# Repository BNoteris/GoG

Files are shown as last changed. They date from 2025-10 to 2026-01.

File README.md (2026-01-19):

# LoRa GPS IoT — PCB Proof-of-Concept

This repository hosts the LoRa GPS IoT proof-of-concept developed as the final project of the High Frequency Circuit Design course at ECAM.
The system integrates a GPS receiver, an ESP32 microcontroller, and a LoRa transceiver to provide location reporting over the LoRaWAN 868 MHz band.
A dedicated custom PCB antenna was designed, simulated and produced for LoRa operation at 868 MHz 
The design was specified in collaboration with an industrial partner and implemented on a 2‑layer FR4 PCB.
Every tool used during this project was open-source.

<div align="center">

</div>

All KiCad & gerber files are available in the [hardware](/hardware) directory.

Antenna simulation can be found in [software](/software).

## Specifications

- Provide GPS-based localization transmission over LoRa at the 868 MHz European LoRa frequency band.
- Support Wi-Fi/BLE communication with ESP32 provided antenna.
- Support multiple power inputs: USB‑C, external battery (2S), and solar panel input.
- Create a compact PCB (≤ 10×10 cm for fabrication on JLCPCB) as a proof of concept.
- Create a custom Inverted‑F Antenna (IFA) tuned to 868 MHz.

## Hardware used

- **ESP32‑C3‑WROOM‑02** — main MCU (USB‑C programming and Wi‑Fi/BLE). Supports SPI and I²C for peripheral interfaces.
- **RFM95 (LoRa) module** — 868 MHz LoRa transceiver (module used without on‑board antenna; external/custom antenna on separate antenna PCB).
- **GPS module AM‑M8Q‑0** — GNSS receiver for latitude/longitude acquisition.
- **BQ25798** — battery charger/power manager supporting USB‑C and solar inputs, designed for a 2S battery configuration.
- **USB‑C connector** — for programming and charging.
- **SMA connector** — RF connector for the custom antenna / external antenna.

## Antenna simulation & testing
### Simulation

Electromagnetic simulations were performed using the Emerge Python‑based EM tool to optimize the antenna geometry for maximum radiated power and minimal reflection at the target frequency.

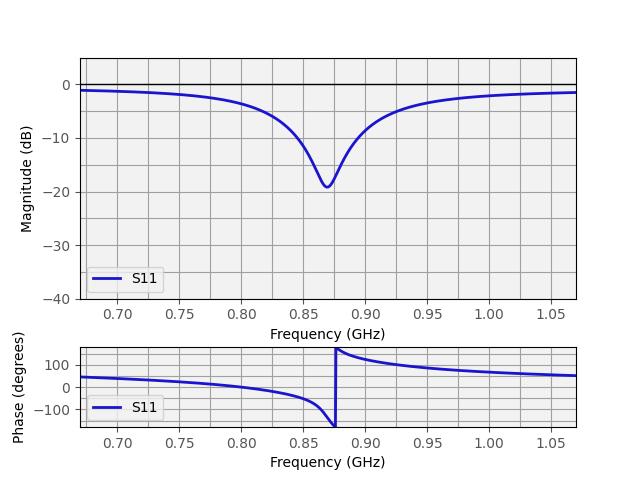
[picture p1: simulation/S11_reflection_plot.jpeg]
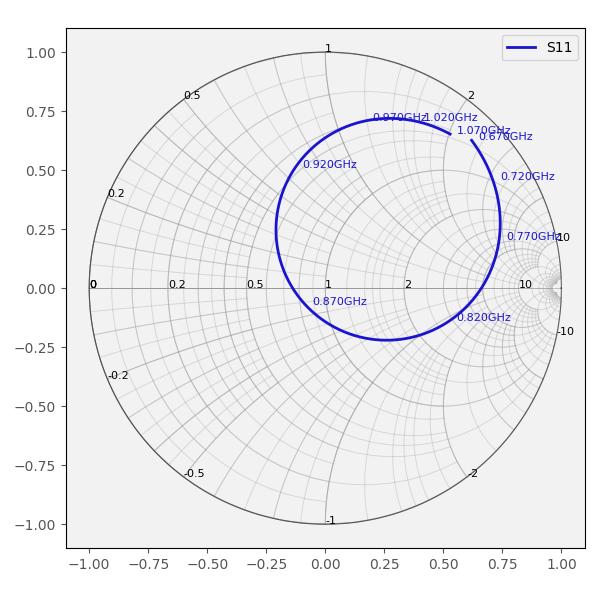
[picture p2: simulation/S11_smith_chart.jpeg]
 | 
:------------:|:--------------------------:
S11 reflection coefficient | Smith chart of reflection coefficient

Primary performance metrics from simulation:
- Minimum simulated **S₁₁ = −17.75 dB at 868 MHz**.
- **−10 dB impedance bandwidth ≈ 50 MHz**, which covers the LoRaWAN band with margin for manufacturing tolerances.

The simulated Smith chart shows the antenna impedance close to the center (near 50 Ω) at 868 MHz; minor adjustments were left open to address real‑world feed/feedline/environment effects.

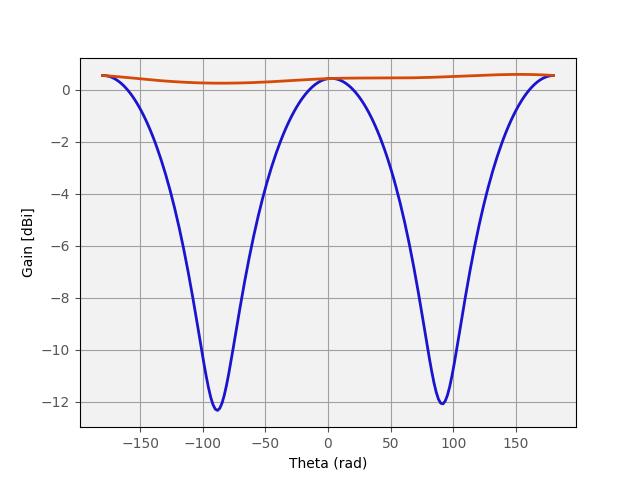
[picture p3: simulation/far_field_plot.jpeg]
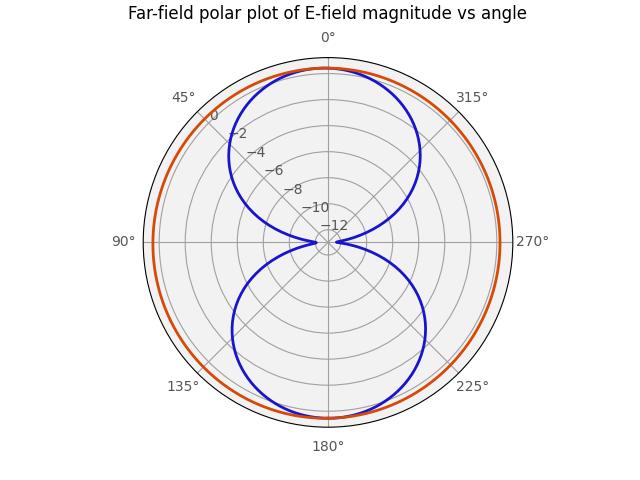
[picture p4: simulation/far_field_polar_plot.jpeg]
 | 
:-----------:|:-------------------:
Far-Field E  |  Polar Far-Field E

<div align="center">
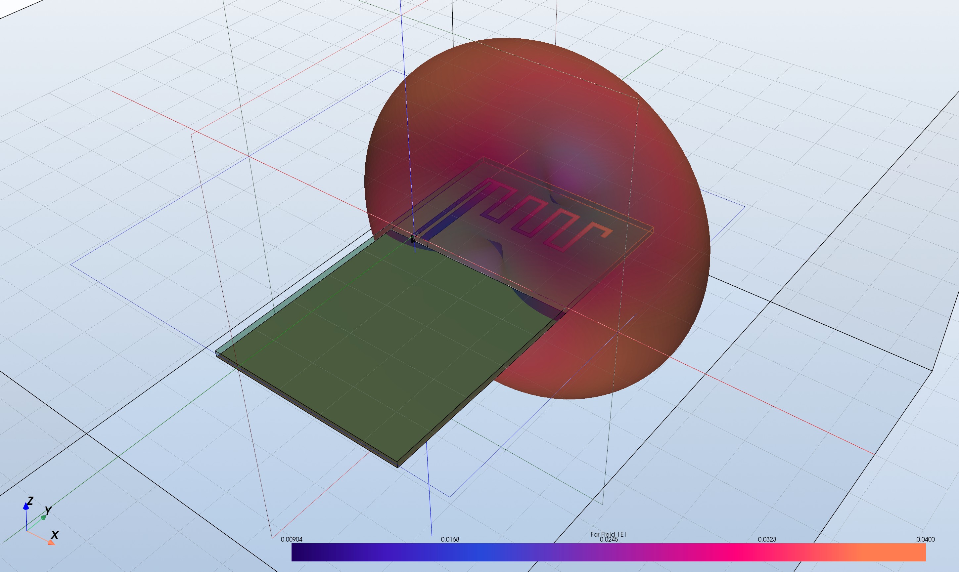
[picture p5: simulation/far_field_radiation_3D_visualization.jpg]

</div>

Far‑field results (normalized E‑field, polar plots and 3D radiation pattern) were generated to verify radiation behaviour

### Hardware validation

<div align="center">

</div>

The manufactured IFA PCB was integrated into the system and validated using a Digital Spectrum Analyzer (DSA) by observing a distinct spectral peak at 868 MHz aligned with the transmission cadence when our custom antenna is sending its packet to a reference antenna tuned to the same band.

 | 
:-------------------------------------------------:|:---------------------------------------------:
Spectrum analysis without custom antenna emission  | Spectrum analysis with custom antenna emission 

Results confirm that the antenna radiates at the intended operating frequency.
Minor nearby spectral peaks were attributed to ambient RF activity.

Limitations: a Vector Network Analyzer (VNA) was not available during testing, preventing direct measurement of the antenna reflection coefficient (S₁₁) on the manufactured part.
This measurement is recommended for a definitive comparison against simulation.

## Improvements

Several enhancements could be considered to further improve the system’s performance 
and quality: 
- As the PCB was intentionally designed with only 2 layers and no ground/power 
planes to observe and measure EMI, but has finally not been done, upgrading our 
design to 4 layers with copper planes would simplify the PCB layout and improve 
EMC. It would, consequently, allow for a more compact design, making it more 
practical.
- Testing our system to EMI interferences would allow to have a better knowledge of 
its real-world performance, as well as its capability to respect HF regulations, a 
mandatory step to deliver our product to the market. 
- Access to a Vector Network Analyzer (or even a LiteVNA) would enable precise 
measurements of the antenna reflection coefficient and matching impedance, 
allowing direct comparison with simulation results and more accurate impedance 
tuning. 
- Testing the system in a real-world environment would provide more information on 
its robustness, in particular, packet loss and communication range and 
performance.

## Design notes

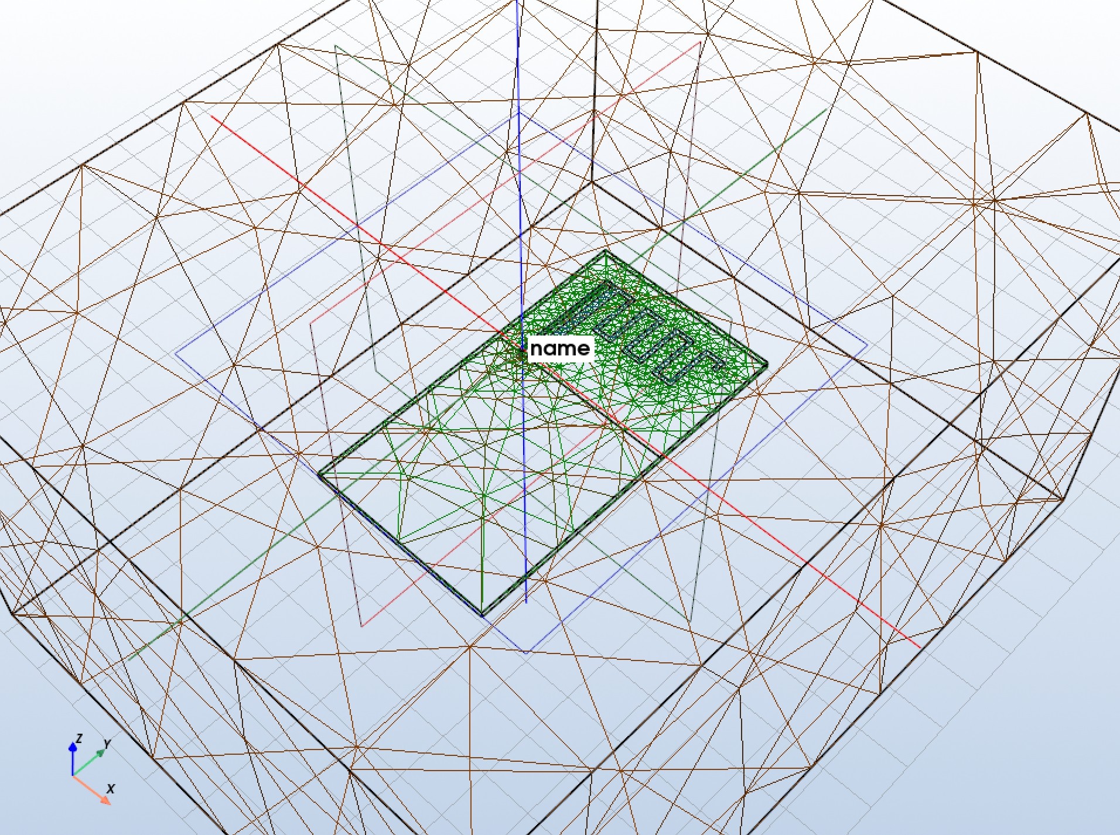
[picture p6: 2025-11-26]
simulation/antenna_mesh_view.jpg

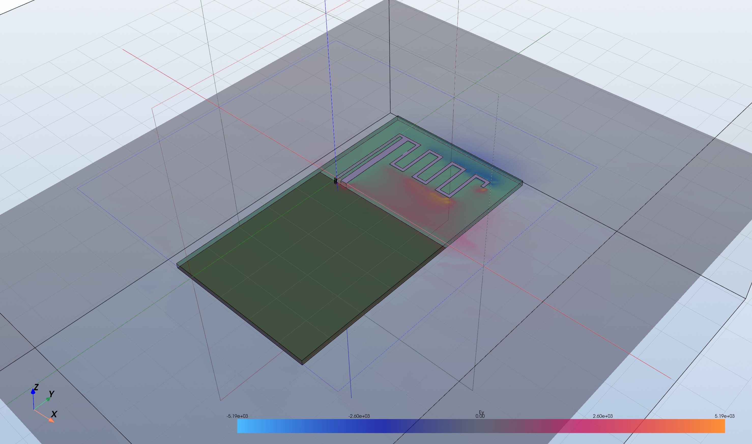
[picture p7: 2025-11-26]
simulation/Ey_3D_visualization.jpg

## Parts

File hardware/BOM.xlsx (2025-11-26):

Reference | Value | Footprint | Description | Qty | JLCPCB Part # | Package
C1 | 10µF | Capacitor_SMD:C_0603_1608Metric | CL10A106MA8NRNC 10uF 25V X5R ±20% 0603 Multilayer Ceramic Capacitor | 1 | C96446 | 0603
C10,C11,C12,C13,C14,C21,C22,C23,C24,C25,C26,C27 | 10u | Capacitor_SMD:C_0805_2012Metric | CL21A106KAYNNNE 10uF 25V X5R ±10% 0805 Multilayer Ceramic Capacitor | 12 | C15850 | 0805
C16,C19 | 47n | GoG_Library:C_0402_1005Metric_JLCPCB | CC0402KRX7R8BB473 25V 47nF X7R ±10% 0402 Multilayer Ceramic Capacitor | 2 | C107020 | 0402
C17 | 4.7u | Capacitor_SMD:C_0603_1608Metric | CL10A475KP8NNNC 10V 4.7uF X5R ±10% 0603 Multilayer Ceramic Capacitor | 1 | C1705 | 0603
C2 | 0.1µF | Capacitor_SMD:C_0603_1608Metric | CL10B104KA8NNNC 100nF 25V X7R ±10% 0603 Multilayer Ceramic Capacitors MLCC - SMD/SMT ROHS | 1 | C1590 | 0603
C28 | 1n | GoG_Library:C_0402_1005Metric_JLCPCB | CL05B102KB5NNNC 1nF 50V X7R ±10% 0402 Multilayer Ceramic Capacitor | 1 | C14442 | 0402
C29 | 0.1u | Capacitor_SMD:C_0603_1608Metric | CC0603KRX7R9BB104 100nF 50V X7R ±10% 0603 Multilayer Ceramic Capacitor | 1 | C14663 | 0603
C3,C7 | 1µF | Capacitor_SMD:C_0603_1608Metric | CL10B105KA8NNNC 1uF 25V X7R ±10% 0603 Multilayer Ceramic Capacitor | 2 | C29936 | 0603
C30 | 10u | Capacitor_SMD:C_0805_2012Metric | HGC0805R5106K350NSLJ 10uF 35V X5R ±10% 0805 Multilayer Ceramic Capacitor | 1 | C33546007 | 0805
C31,C32 | 22u | Capacitor_SMD:C_0805_2012Metric | CL21A226MAQNNNE 22uF 25V X5R ±20% 0805 Multilayer Ceramic Capacitor | 2 | C45783 | 0805
C4 | 100nF | Capacitor_SMD:C_0603_1608Metric | CL10B104KA8NNNC 100nF 25V X7R ±10% 0603 Multilayer Ceramic Capacitors MLCC - SMD/SMT ROHS | 1 | C1590 | 0603
C5,C6 | (NC) | Resistor_SMD:R_0805_2012Metric_Pad1.20x1.40mm_HandSolder | Unpolarized capacitor | 2 | / | 0805 | Non connect capacitors for antenna : Remove from assembly BOM
C8,C9,C15,C18,C20 | 0.1u | GoG_Library:C_0402_1005Metric_JLCPCB | CL05A104KA5NNNC 100nF 25V X5R ±10% 0402 Multilayer Ceramic Capacitor | 5 | C100072 | 0402
D1,D2 | R_LED | LED_SMD:LED_0603_1608Metric | MEIHUA MHT192DUGCT LED 2.3V~2.8V 518nm 565mcd 5mA 60mW Green | 2 | C7470862 | 0603
D3 | D_Zener | Diode_SMD:D_SOD-123 | ONSEMI MMSZ4697T1G Zener diode 10V 1uA@7.6V 500mW 9.5V~10.5V | 1 | C48870 | SOD-123
D4,D5 | D_Zener | Diode_SMD:D_SOD-123 | ONSEMI MMSZ4699T1G Zener diode 12V 500mW 50nA@9.1V | 2 | C97772 | SOD-123
D6 | LED | LED_SMD:LED_0603_1608Metric | MEIHUA MHT192DUGCT LED 2.3V~2.8V 518nm 565mcd 5mA 60mW Green | 1 | C7470862 | 0603
J1 | USB_C_Receptacle_USB2.0_16P | Connector_USB:USB_C_Receptacle_GCT_USB4105-xx-A_16P_TopMnt_Horizontal | TYPE-C16PIN USB 2.0-only 16P Type-C Receptacle connector | 1 | C393939 | SMD
J10 | Conn_01x03 | Connector_PinHeader_2.54mm:PinHeader_1x03_P2.54mm_Vertical | ZX-PZ2.54-1-3PZZ 1x3P 2.54mm Pin Header | 1 | C7501261 | Plugin,P=2.54mm
J11 | Conn_01x02 | Connector_PinHeader_2.54mm:PinHeader_1x02_P2.54mm_Vertical | ZX-PZ2.54-1-2PZZ 1x2P 2.54mm Pin Header | 1 | C7501260 | Plugin,P=2.54mm
J2,J4 | Conn_01x02_Pin | Connector_PinHeader_2.54mm:PinHeader_1x02_P2.54mm_Vertical | ZX-PZ2.54-1-2PZZ 1x2P 2.54mm Pin Header | 2 | C7501260 | Plugin,P=2.54mm
J3 | Conn_01x04_Pin | Connector_PinHeader_2.54mm:PinHeader_1x04_P2.54mm_Vertical | ZX-PZ2.54-1-4PZZ 1x4P 2.54mm Pin Header | 1 | C7501262 | Plugin,P=2.54mm
J5 | 85201239 | SMA-85201239:HUBER_SUHNER_85201239 | -45℃~+80℃ 1 14.6mm 4.65mm 50Ω 6GHz Board Side Inner Bore Plugin Coaxial Connectors (RF) ROHS | 1 | C7498154 | Plugin
J6,J7 | Conn_01x04_Pin | Connector_JST:JST_XH_B4B-XH-A_1x04_P2.50mm_Vertical | B4B-XH-AM(LF)(SN) 1x4P 2.5mm JST connector | 2 | C161871 | Plugin,P=2.5mm
J8 | Screw_Terminal_01x02 | GoG_Library:TerminalBlock_WJ126V-5.0-2P_1x02_P5.00mm | WJ126V-5.0-2P 1x2P P=5mm Screw Terminal Block | 1 | C8404 | Plugin,P=5mm
J9 | Conn_01x02 | Connector_JST:JST_XH_B2B-XH-A_1x02_P2.50mm_Vertical | B2B-XH-A(LF)(SN) 1x2P P=2.5mm XH JST connector | 1 | C158012 | Plugin,P=2.5mm
L1 | 2.2u | GoG_Library:MDA5030-2R2M | MDA5030-2R2M Inductor 2.2uH 21.6mΩ 6.5A 6.5A ±20% SMD, 5.7x5.2mm | 1 | C2847475 | SMD, 5.7x5.2mm
L2 | 3.9u | Inductor_SMD:L_Sunlord_SWPA4030S | SWPA4030S3R9MT 2.1A 3.9uH 3A 74mΩ ±20% SMD,4x4mm Power Inductor | 1 | C96899 | SMD, 4x4mm
Q1 | Q_PMOS | Package_TO_SOT_SMD:SOT-23 | P-MOSFET transistor | 1 | C5350989 | SOT-23
Q2,Q3,Q4,Q5 | Q_NMOS | Package_TO_SOT_SMD:SOT-23 | N-MOSFET transistor | 4 | C2938367 | SOT-23
R1,R10 | 1k | Resistor_SMD:R_0603_1608Metric | RC0603FR-071KL 100mW 1kΩ 75V Thick Film Resistor ±1% 0603 | 2 | C22548 | 0603
R11,R12 | 470 | Resistor_SMD:R_0603_1608Metric | RC0603FR-07470RL 100mW 470Ω 75V Thick Film Resistor ±1% 0603 | 2 | C114669 | 0603
R13,R14 | 22 | Resistor_SMD:R_0603_1608Metric | RC0603FR-0722RL 100mW 22Ω 75V Thick Film Resistor ±1% 0603 | 2 | C107701 | 0603
R15,R17 | 300 | Resistor_SMD:R_0603_1608Metric | RC0603FR-07300RL -55℃~+155℃ 100mW 300Ω 75V Thick Film Resistor ±1% ±100ppm/℃ 0603 | 2 | C114617 | 0603
R16,R25 | 100k | GoG_Library:R_0402_1005Metric_JLCPCB | RC0402FR-07100KL -55℃~+155℃ 100kΩ 50V 62.5mW Thick Film Resistor ±1% ±100ppm/℃ 0402 | 2 | C60491 | 0402
R18 | 10k | GoG_Library:R_0402_1005Metric_JLCPCB | RC0402FR-0710KL -55℃~+155℃ 10kΩ 50V 62.5mW Thick Film Resistor ±1% ±100ppm/℃ 0402 | 1 | C60490 | 0402
R19 | 2.2k | GoG_Library:R_0402_1005Metric_JLCPCB | RC0402JR-072K2L -55℃~+155℃ 2.2kΩ 50V 62.5mW Thick Film Resistor ±100ppm/℃ ±5% 0402 | 1 | C163447 | 0402
R2,R3,R6 | 10k | Resistor_SMD:R_0603_1608Metric | RC0603FR-0710KL 100mW 10kΩ 75V Thick Film Resistor ±1% 0603 | 3 | C98220 | 0603
R20 | 100 | GoG_Library:R_0402_1005Metric_JLCPCB | RC0402FR-07100RL -55℃~+155℃ 100Ω 50V 62.5mW Thick Film Resistor ±1% ±100ppm/℃ 0402 | 1 | C106232 | 0402
R21 | 5.1k | GoG_Library:R_0402_1005Metric_JLCPCB | RC0402FR-075K1L -55℃~+155℃ 5.1kΩ 50V 62.5mW Thick Film Resistor ±1% ±100ppm/℃ 0402 | 1 | C105872 | 0402
R22 | 120k | GoG_Library:R_0402_1005Metric_JLCPCB | RC0402FR-07120KL -55℃~+155℃ 120kΩ 50V 62.5mW Thick Film Resistor ±1% ±100ppm/℃ 0402 | 1 | C93945 | 0402
R23 | 8.2k | GoG_Library:R_0402_1005Metric_JLCPCB | RC0402FR-078K2L -55℃~+155℃ 50V 62.5mW 8.2kΩ Thick Film Resistor ±1% ±100ppm/℃ 0402 | 1 | C137929 | 0402
R24 | 30k | GoG_Library:R_0402_1005Metric_JLCPCB | RC0402FR-0730KL -55℃~+155℃ 30kΩ 50V 62.5mW Thick Film Resistor ±1% ±100ppm/℃ 0402 | 1 | C138008 | 0402
R4,R5 | 4.7k | Resistor_SMD:R_0603_1608Metric | RC0603FR-074K7L 100mW 4.7kΩ 75V Thick Film Resistor ±1% 0603 | 2 | C99782 | 0603
R7,R8 | 5k1 | Resistor_SMD:R_0603_1608Metric | RC0603FR-075K1L 100mW 5.1kΩ 75V Thick Film Resistor ±1% 0603 | 2 | C105580 | 0603
R9 | 0 | Resistor_SMD:R_0805_2012Metric_Pad1.20x1.40mm_HandSolder | PMR10EZPJ000 0Ω 500mW Shunt Resistor 0805 | 1 | C2842889 | 0805
SW1,SW2 | SW_Omron_B3FS | Button_Switch_SMD:SW_SPST_Omron_B3FS-101xP | Omron B3FS-1010P 6x6mm single pole normally-open tactile switch | 2 | C231324 | SMD-4P,6.3x6mm
TH1 | 10k | GoG_Library:Thermistor NTC | Vishay NTCLE413E2103F102L NTC Thermistor 10k 3435K | 1 | - | - | Get from Farnell : 2492885
U1 | ESP32-C3-WROOM-02 | RF_Module:ESP32-C3-WROOM-02 | 802.11 b/g/n Wi-Fi and Bluetooth 5 module, ESP32-C3 SoC, RISC-V microprocessor, On-board antenna | 1 | C2934560 | LCC-18
U2 | USBLC6-2SC6 | Package_TO_SOT_SMD:SOT-23-6 | USBLC6-2SC6 Very low capacitance ESD protection diode, 2 data-line, SOT-23-6 | 1 | C7519 | SOT-23-6L
U3 | RFM95W-868S2 | GoG_Library:HOPERF_RFM9XW_SMD | Low power long range transceiver module, SPI and parallel interface, 868 MHz, spreading factor 6 to12, bandwidth 7.8 to 500kHz, -111 to -148 dBm, SMD-16, DIP-16 | 1 | C2844472 | SMD,16x16mm
U4 | SAM-M8Q | RF_GPS:ublox_SAM-M8Q | GPS ublox M8 variant | 1 | C5447387 | SMD-20P,15x15mm | Out of stock
U5 | BQ25798RQMR | BQ25798RQMR:IC_BQ25798RQMR | -40℃~+85℃ 17uA 1~4 3.6V~24V 5A Charging IC I2C Lithium Battery Support QFN-29(4x4) Battery Management | 1 | C2876593 | QFN-29(4x4) | Out of stock
U6 | AP63203WU | Package_TO_SOT_SMD:TSOT-23-6 | 2A, 1.1MHz Buck DC/DC Converter, fixed 3.3V output voltage, TSOT-23-6 | 1 | C780769 | TSOT-23-6

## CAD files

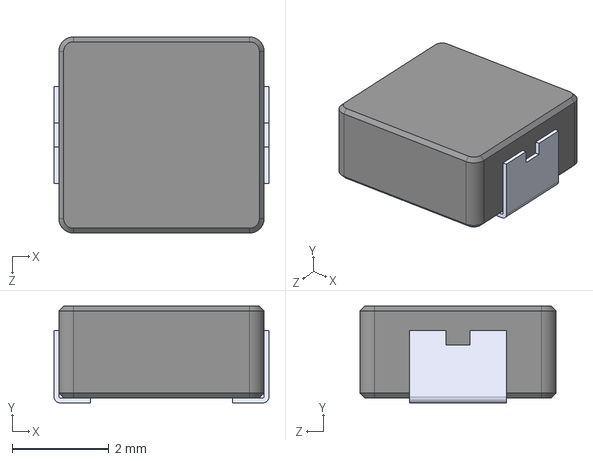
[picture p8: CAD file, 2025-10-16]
hardware/Project library/SRP4020TA-5R6M/SRP4020TA-5R6M.step
4.45 x 2.00 x 4.06 mm

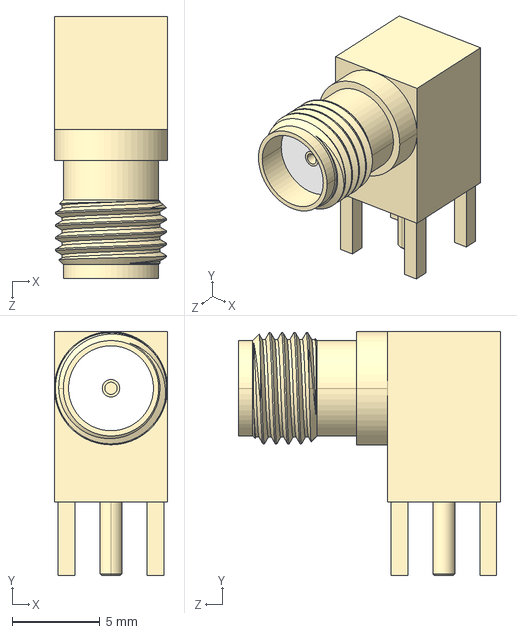
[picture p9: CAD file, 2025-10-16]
hardware/Project library/SMA-85201239/85201239.step
6.46 x 13.9 x 15.0 mm

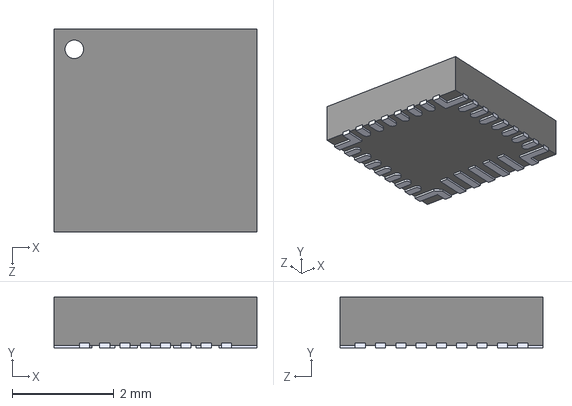
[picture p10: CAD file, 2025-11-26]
hardware/Project library/ul_BQ25798RQMR/KiCADv6/BQ25798RQMR.step
4.00 x 1.00 x 4.00 mm

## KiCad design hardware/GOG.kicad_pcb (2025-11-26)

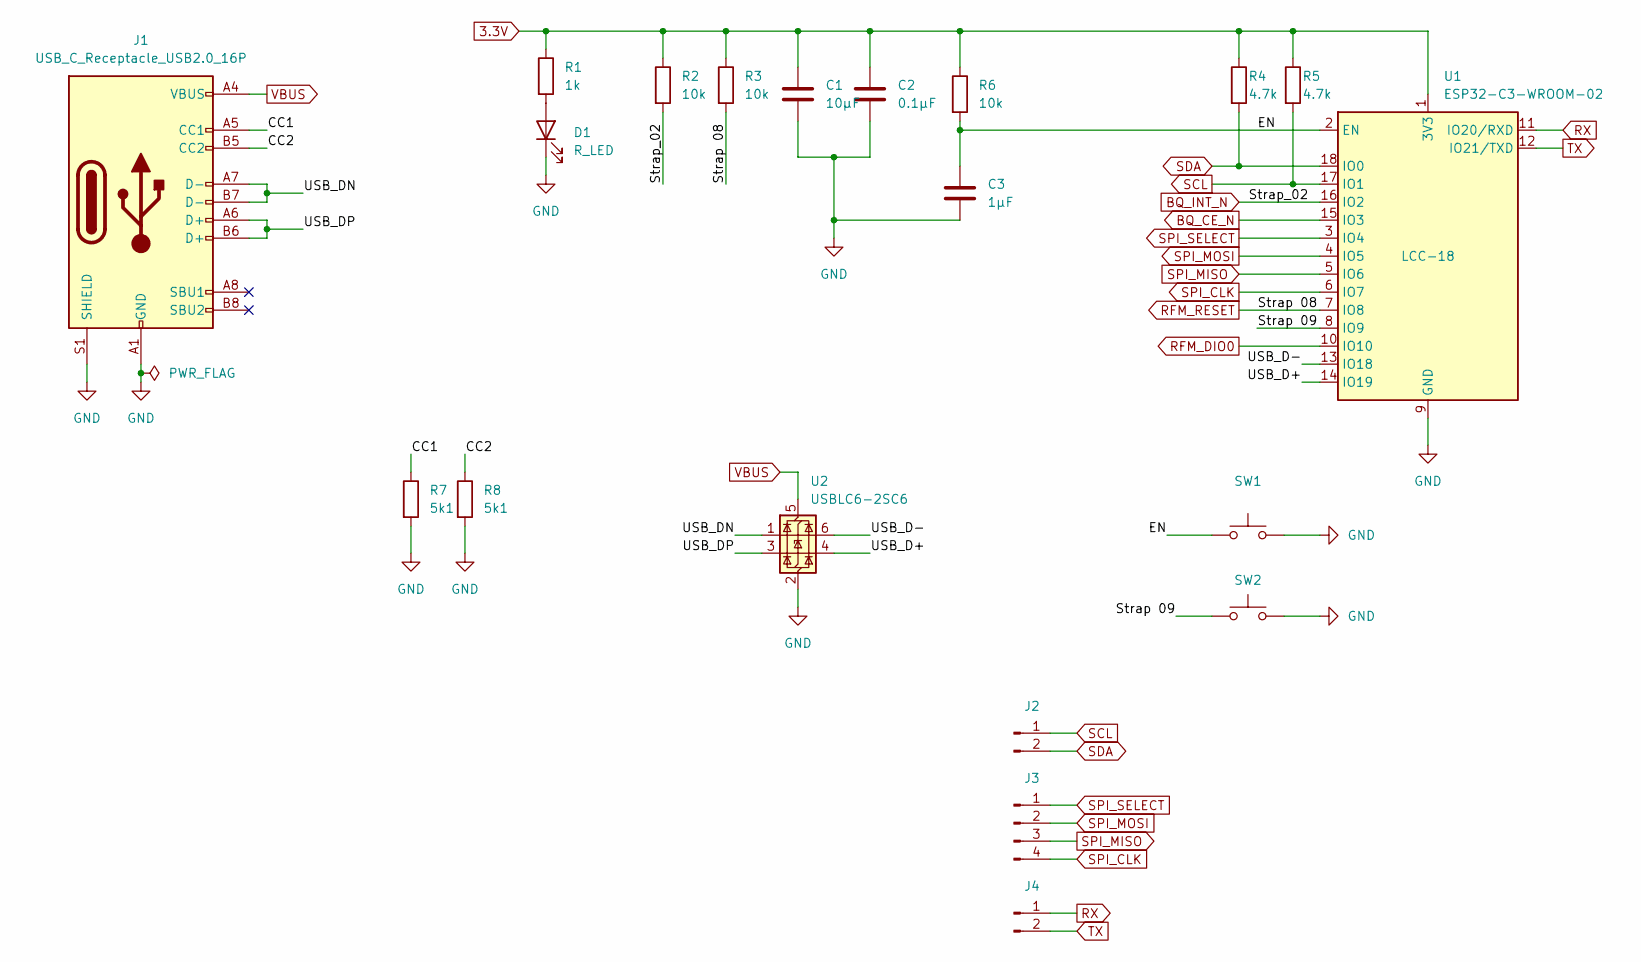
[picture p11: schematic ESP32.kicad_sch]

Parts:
C1: 10µF; C_0603_1608Metric; JLCPCB Part # C96446
C2: 0.1µF; C_0603_1608Metric; JLCPCB Part # C1590
C3: 1µF; C_0603_1608Metric; JLCPCB Part # C29936
D1: R_LED; LED_0603_1608Metric; JLCPCB Part # C7470862
J1: USB_C_Receptacle_USB2.0_16P; USB_C_Receptacle_GCT_USB4105-xx-A_16P_TopMnt_Horizontal; JLCPCB Part # C393939
J2, J4: Conn_01x02_Pin; PinHeader_1x02_P2.54mm_Vertical; JLCPCB Part # C7501260
J3: Conn_01x04_Pin; PinHeader_1x04_P2.54mm_Vertical; JLCPCB Part # C7501262
R1: 1k; R_0603_1608Metric; JLCPCB Part # C22548
R2, R3, R6: 10k; R_0603_1608Metric; JLCPCB Part # C98220
R4, R5: 4.7k; R_0603_1608Metric; JLCPCB Part # C99782
R7, R8: 5k1; R_0603_1608Metric; JLCPCB Part # C105580
SW1, SW2: SW_Omron_B3FS; SW_SPST_Omron_B3FS-101xP; JLCPCB Part # C231324
U1: ESP32-C3-WROOM-02; JLCPCB Part # C2934560
U2: USBLC6-2SC6; SOT-23-6; JLCPCB Part # C7519

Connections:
3.3V: C1.1, C2.1, R1.1, R2.1, R3.1, R4.1, R5.1, R6.1, U1.1 (3V3); also elsewhere on the board
/ESP32/CC1: J1.A5 (CC1), R7.1
/ESP32/CC2: J1.B5 (CC2), R8.1
/ESP32/EN: C3.1, R6.2, SW1.1, U1.2 (EN)
/ESP32/Strap 09: SW2.1, U1.8 (IO9)
/ESP32/USB_D+: U1.14 (IO19), U2.4 (I/O2)
/ESP32/USB_D-: U1.13 (IO18), U2.6 (I/O1)
/ESP32/USB_DN: J1.A7 (D-), J1.B7 (D-), U2.1 (I/O1)
/ESP32/USB_DP: J1.A6 (D+), J1.B6 (D+), U2.3 (I/O2)
BQ_CE_N: U1.15 (IO3); also elsewhere on the board
BQ_INT_N: R2.2, U1.16 (IO2); also elsewhere on the board
GND: C1.2, C2.2, C3.2, D1.1 (K), J1.A1 (GND), J1.A12 (GND), J1.B1 (GND), J1.B12 (GND), J1.S1 (SHIELD), R7.2, R8.2, SW1.2, SW2.2, U1.9 (GND), U1.19 (GND), U2.2 (GND); also elsewhere on the board
unnamed: D1.2 (A), R1.2
RFM_DIO0: U1.10 (IO10); also elsewhere on the board
RFM_RESET: R3.2, U1.7 (IO8); also elsewhere on the board
RX: J4.1, U1.11 (IO20/RXD)
SCL: J2.1, R5.2, U1.17 (IO1); also elsewhere on the board
SDA: J2.2, R4.2, U1.18 (IO0); also elsewhere on the board
SPI_CLK: J3.4, U1.6 (IO7); also elsewhere on the board
SPI_MISO: J3.3, U1.5 (IO6); also elsewhere on the board
SPI_MOSI: J3.2, U1.4 (IO5); also elsewhere on the board
SPI_SELECT: J3.1, U1.3 (IO4); also elsewhere on the board
TX: J4.2, U1.12 (IO21/TXD)
VBUS: J1.A4 (VBUS), J1.A9 (VBUS), J1.B4 (VBUS), J1.B9 (VBUS), U2.5 (VBUS); also elsewhere on the board

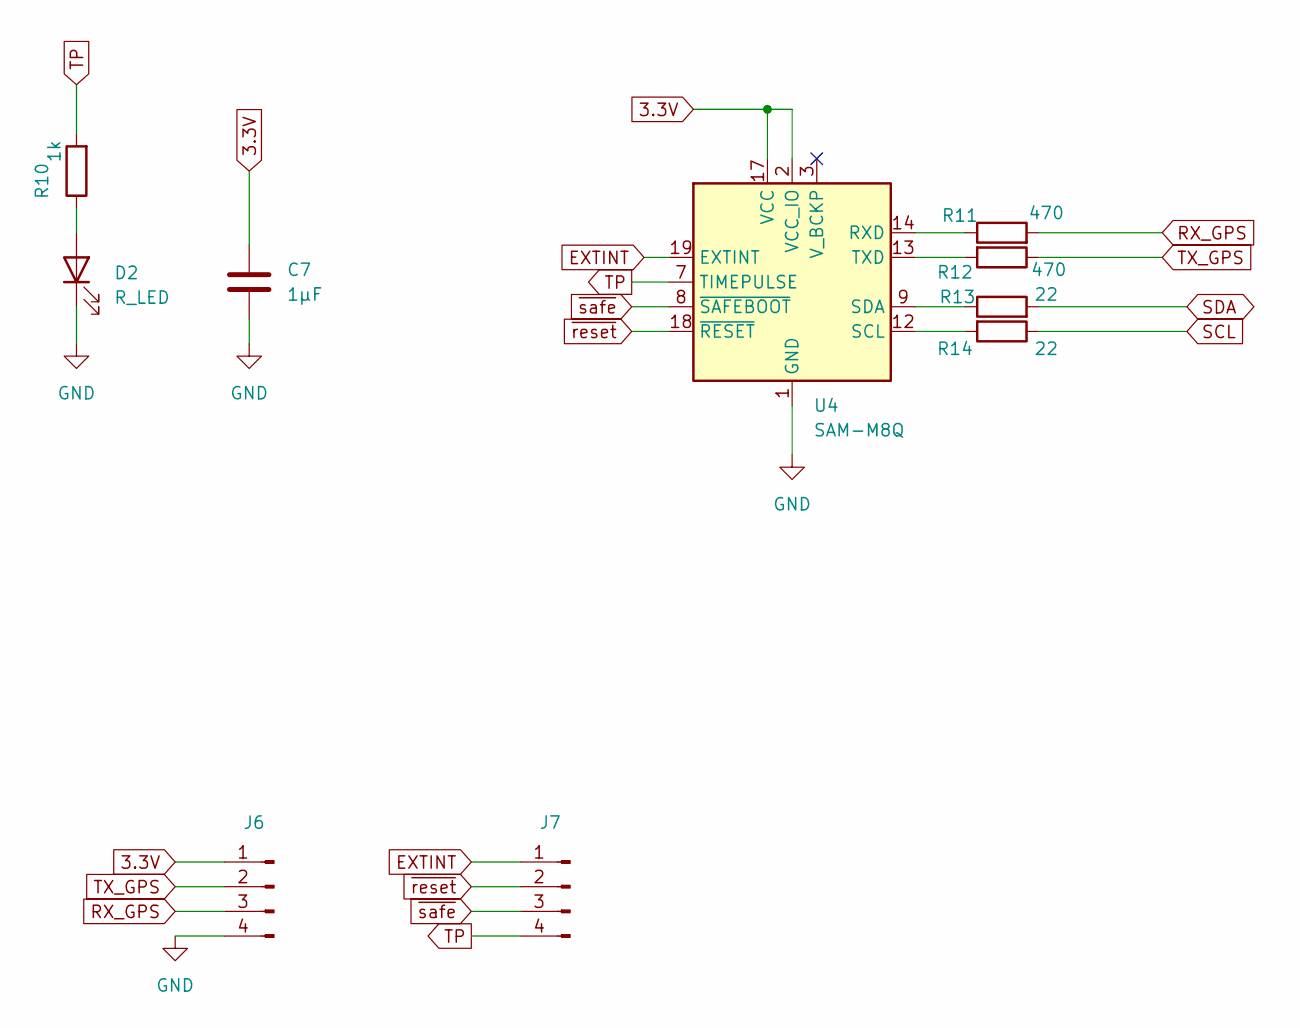
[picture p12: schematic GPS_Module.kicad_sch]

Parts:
C7: 1µF; C_0603_1608Metric; JLCPCB Part # C29936
D2: R_LED; LED_0603_1608Metric; JLCPCB Part # C7470862
J6, J7: Conn_01x04_Pin; JST_XH_B4B-XH-A_1x04_P2.50mm_Vertical; JLCPCB Part # C161871
R10: 1k; R_0603_1608Metric; JLCPCB Part # C22548
R11, R12: 470; R_0603_1608Metric; JLCPCB Part # C114669
R13, R14: 22; R_0603_1608Metric; JLCPCB Part # C107701
U4: SAM-M8Q; ublox_SAM-M8Q; JLCPCB Part # C5447387

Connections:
3.3V: C7.1, J6.1, U4.2 (VCC_IO), U4.17 (VCC); also elsewhere on the board
EXTINT: J7.1, U4.19 (EXTINT)
GND: C7.2, D2.1 (K), J6.4, U4.1 (GND), U4.4 (GND), U4.5 (GND), U4.6 (GND), U4.10 (GND), U4.11 (GND), U4.15 (GND), U4.16 (GND), U4.20 (GND); also elsewhere on the board
unnamed: D2.2 (A), R10.1
unnamed: R11.1, U4.14 (RXD)
unnamed: R14.2, U4.12 (SCL)
unnamed: R13.1, U4.9 (SDA)
unnamed: R12.2, U4.13 (TXD)
RX_GPS: J6.3, R11.2
SCL: R14.1; also elsewhere on the board
SDA: R13.2; also elsewhere on the board
TP: J7.4, R10.2, U4.7 (TIMEPULSE)
TX_GPS: J6.2, R12.1
~reset: J7.2, U4.18 (~RESET)
~safe: J7.3, U4.8 (~SAFEBOOT)

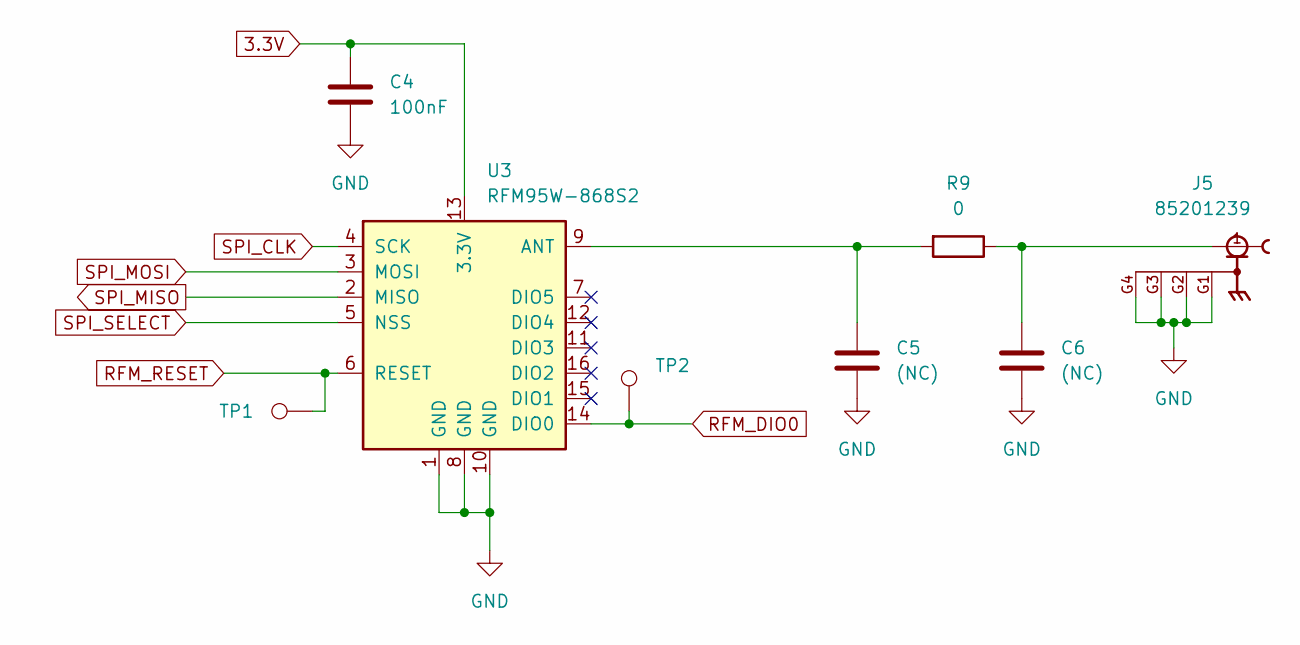
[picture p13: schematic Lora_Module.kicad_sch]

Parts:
C4: 100nF; C_0603_1608Metric; JLCPCB Part # C1590
C5, C6: (NC); R_0805_2012Metric_Pad1.20x1.40mm_HandSolder; JLCPCB Part # /
J5: 85201239; HUBER_SUHNER_85201239; PARTREV A; JLCPCB Part # C7498154
R9: 0; R_0805_2012Metric_Pad1.20x1.40mm_HandSolder; JLCPCB Part # C2842889
TP1, TP2: TestPoint; TestPoint_Pad_D1.5mm_JLCPCB
U3: RFM95W-868S2; HOPERF_RFM9XW_SMD; JLCPCB Part # C2844472

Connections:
3.3V: C4.1, U3.13 (3.3V); also elsewhere on the board
GND: C4.2, C5.2, C6.2, J5.G1, J5.G2, J5.G3, J5.G4, U3.1 (GND), U3.8 (GND), U3.10 (GND); also elsewhere on the board
unnamed: C6.1, J5.1, R9.1
unnamed: C5.1, R9.2, U3.9 (ANT)
RFM_DIO0: TP2.1, U3.14 (DIO0); also elsewhere on the board
RFM_RESET: TP1.1, U3.6 (RESET); also elsewhere on the board
SPI_CLK: U3.4 (SCK); also elsewhere on the board
SPI_MISO: U3.2 (MISO); also elsewhere on the board
SPI_MOSI: U3.3 (MOSI); also elsewhere on the board
SPI_SELECT: U3.5 (NSS); also elsewhere on the board

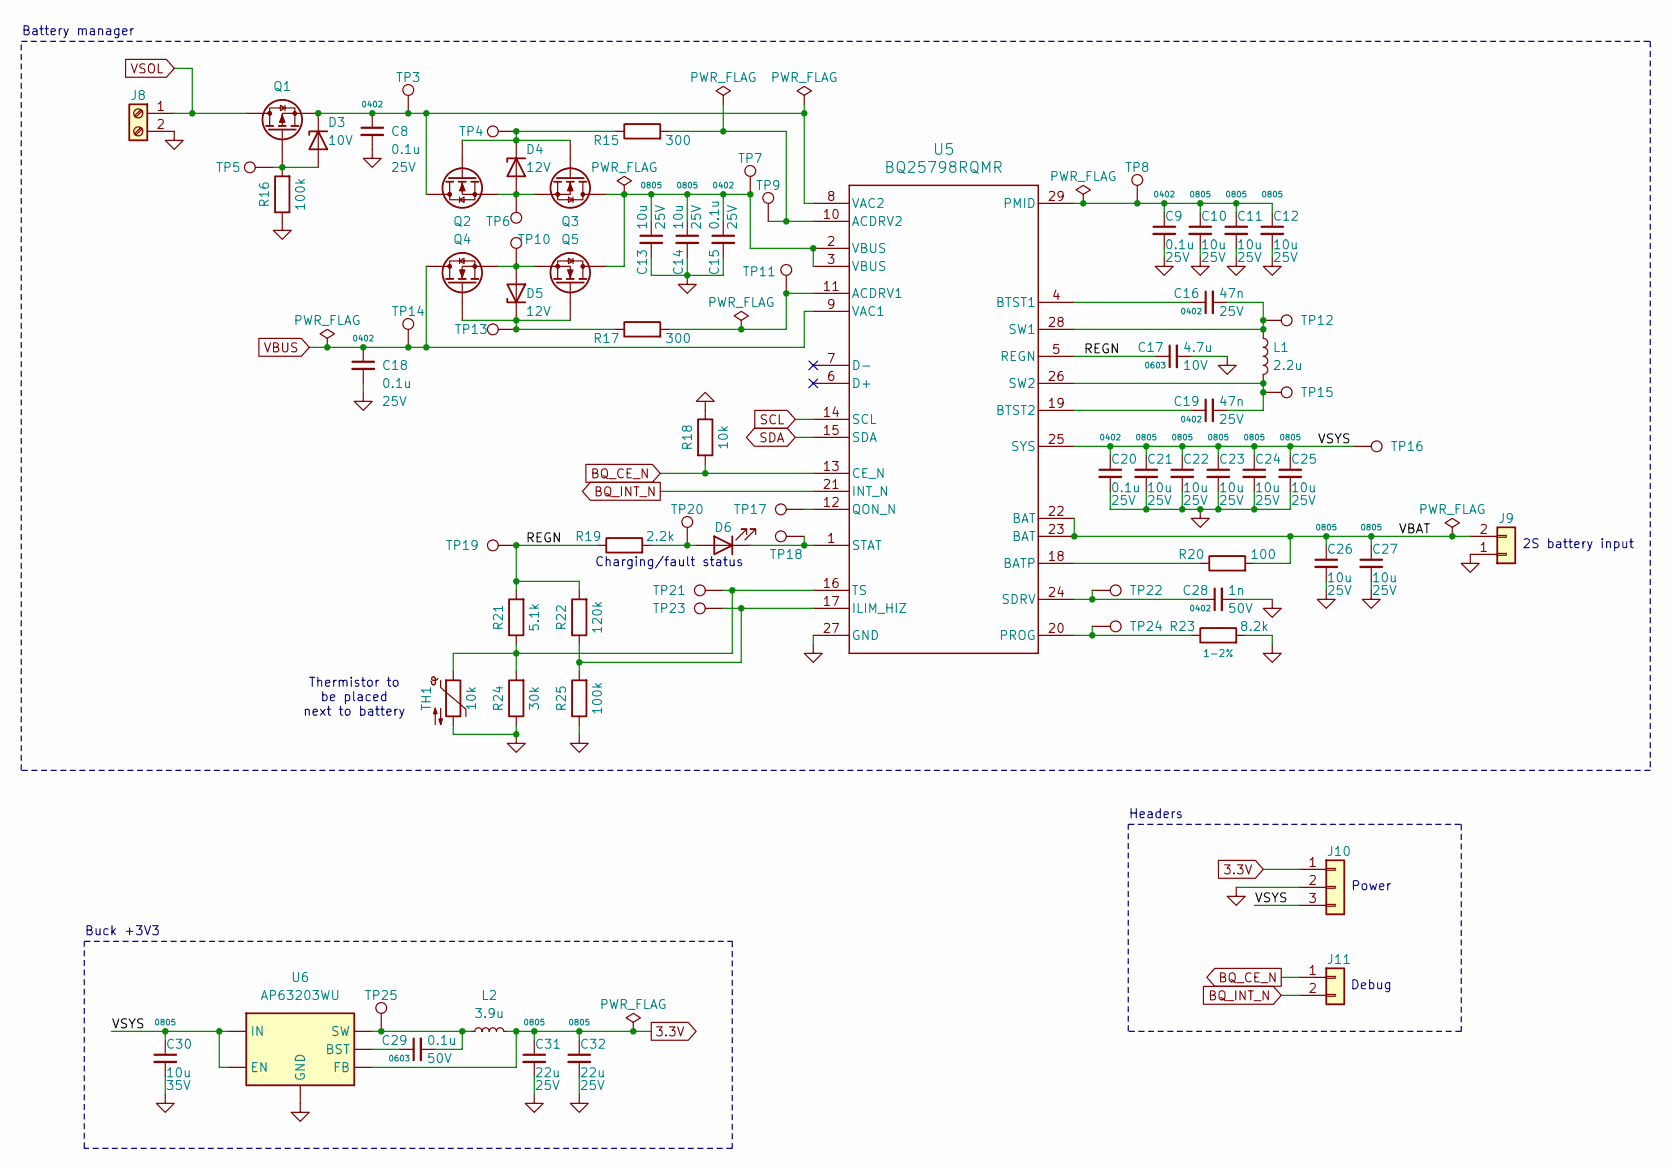
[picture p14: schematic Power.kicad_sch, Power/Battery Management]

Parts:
C8, C9, C15, C18, C20: 0.1u; C_0402_1005Metric_JLCPCB; Voltage 25V; JLCPCB Part # C100072
C10, C11, C12, C13, C14, C21, C22, C23, C24, C25, C26, C27: 10u; C_0805_2012Metric; Voltage 25V; JLCPCB Part # C15850
C16, C19: 47n; C_0402_1005Metric_JLCPCB; Voltage 25V; JLCPCB Part # C107020
C17: 4.7u; C_0603_1608Metric; Voltage 10V; JLCPCB Part # C1705
C28: 1n; C_0402_1005Metric_JLCPCB; Voltage 50V; JLCPCB Part # C14442
C29: 0.1u; C_0603_1608Metric; Voltage 50V; JLCPCB Part # C14663
C30: 10u; C_0805_2012Metric; Voltage 35V; JLCPCB Part # C33546007
C31, C32: 22u; C_0805_2012Metric; Voltage 25V; JLCPCB Part # C45783
D3: D_Zener; D_SOD-123; Voltage 10V; JLCPCB Part # C48870
D4, D5: D_Zener; D_SOD-123; Voltage 12V; JLCPCB Part # C97772
D6: LED; LED_0603_1608Metric; JLCPCB Part # C7470862
J8: Screw_Terminal_01x02; TerminalBlock_WJ126V-5.0-2P_1x02_P5.00mm; JLCPCB Part # C8404
J9: Conn_01x02; JST_XH_B2B-XH-A_1x02_P2.50mm_Vertical; JLCPCB Part # C158012
J10: Conn_01x03; PinHeader_1x03_P2.54mm_Vertical; JLCPCB Part # C7501261
J11: Conn_01x02; PinHeader_1x02_P2.54mm_Vertical; JLCPCB Part # C7501260
L1: 2.2u; MDA5030-2R2M; JLCPCB Part # C2847475
L2: 3.9u; L_Sunlord_SWPA4030S; JLCPCB Part # C96899
Q1: Q_PMOS; SOT-23; JLCPCB Part # C5350989
Q2, Q3, Q4, Q5: Q_NMOS; SOT-23; JLCPCB Part # C2938367
R15, R17: 300; R_0603_1608Metric; JLCPCB Part # C114617
R16, R25: 100k; R_0402_1005Metric_JLCPCB; JLCPCB Part # C60491
R18: 10k; R_0402_1005Metric_JLCPCB; JLCPCB Part # C60490
R19: 2.2k; R_0402_1005Metric_JLCPCB; JLCPCB Part # C163447
R20: 100; R_0402_1005Metric_JLCPCB; JLCPCB Part # C106232
R21: 5.1k; R_0402_1005Metric_JLCPCB; JLCPCB Part # C105872
R22: 120k; R_0402_1005Metric_JLCPCB; JLCPCB Part # C93945
R23: 8.2k; R_0402_1005Metric_JLCPCB; Tolerence 1-2%; JLCPCB Part # C137929
R24: 30k; R_0402_1005Metric_JLCPCB; JLCPCB Part # C138008
TH1: 10k; Thermistor NTC
TP3, TP4, TP5, TP6, TP7, TP8, TP9, TP10, TP11, TP12, TP13, TP14, TP15, TP16, TP17, TP18, TP19, TP20, TP21, TP22, TP23, TP24, TP25: TestPoint; TestPoint_Pad_D1.5mm_JLCPCB
U5: BQ25798RQMR; IC_BQ25798RQMR; JLCPCB Part # C2876593
U6: AP63203WU; TSOT-23-6; JLCPCB Part # C780769

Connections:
3.3V: C31.1, C32.1, J10.1, L2.2, U6.1 (FB); also elsewhere on the board
/Power/REGN: C17.1, R19.1, R21.2, R22.2, TP19.1, U5.5 (REGN)
/Power/VBAT: C26.1, C27.1, J9.2, R20.2, U5.22 (BAT), U5.23 (BAT)
/Power/VSYS: C20.1, C21.1, C22.1, C23.1, C24.1, C25.1, C30.1, J10.3, TP16.1, U5.25 (SYS), U6.2 (EN), U6.3 (IN)
BQ_CE_N: J11.1, R18.2, U5.13 (CE_N); also elsewhere on the board
BQ_INT_N: J11.2, U5.21 (INT_N); also elsewhere on the board
GND: C8.2, C9.2, C10.2, C11.2, C12.2, C13.2, C14.2, C15.2, C17.2, C18.2, C20.2, C21.2, C22.2, C23.2, C24.2, C25.2, C26.2, C27.2, C28.2, C30.2, C31.2, C32.2, J8.2, J9.1, J10.2, R16.1, R18.1, R23.2, R24.1, R25.1, TH1.2, U5.27 (GND), U6.4 (GND); also elsewhere on the board
unnamed: D3.2 (A), Q1.1 (G), R16.2, TP5.1
unnamed: C8.1, D3.1 (K), Q1.2 (S), Q2.3 (D), TP3.1, U5.8 (VAC2)
unnamed: D4.2 (A), Q2.2 (S), Q3.2 (S), TP6.1
unnamed: D4.1 (K), Q2.1 (G), Q3.1 (G), R15.1, TP4.1
unnamed: D5.2 (A), Q4.2 (S), Q5.2 (S), TP10.1
unnamed: D5.1 (K), Q4.1 (G), Q5.1 (G), R17.1, TP13.1
unnamed: D6.2 (A), R19.2, TP20.1
unnamed: D6.1 (K), TP18.1, U5.1 (STAT)
unnamed: C13.1, C14.1, C15.1, Q3.3 (D), Q5.3 (D), TP7.1, U5.2 (VBUS), U5.3 (VBUS)
unnamed: R17.2, TP11.1, U5.11 (ACDRV1)
unnamed: R15.2, TP9.1, U5.10 (ACDRV2)
unnamed: R20.1, U5.18 (BATP)
unnamed: C16.1, U5.4 (BTST1)
unnamed: C19.1, U5.19 (BTST2)
unnamed: R22.1, R25.2, TP23.1, U5.17 (ILIM_HIZ)
unnamed: C9.1, C10.1, C11.1, C12.1, TP8.1, U5.29 (PMID)
unnamed: R23.1, TP24.1, U5.20 (PROG)
unnamed: TP17.1, U5.12 (QON_N)
unnamed: C28.1, TP22.1, U5.24 (SDRV)
unnamed: C16.2, L1.1, TP12.1, U5.28 (SW1)
unnamed: C19.2, L1.2, TP15.1, U5.26 (SW2)
unnamed: R21.1, R24.2, TH1.1, TP21.1, U5.16 (TS)
unnamed: C29.1, U6.6 (BST)
unnamed: C29.2, L2.1, TP25.1, U6.5 (SW)
SCL: U5.14 (SCL); also elsewhere on the board
SDA: U5.15 (SDA); also elsewhere on the board
VBUS: C18.1, Q4.3 (D), TP14.1, U5.9 (VAC1); also elsewhere on the board
VSOL: J8.1, Q1.3 (D)

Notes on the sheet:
Debug
Buck +3V3
Headers
Thermistor to be placed next to battery
Charging/fault status
2S battery input
Power
Battery manager

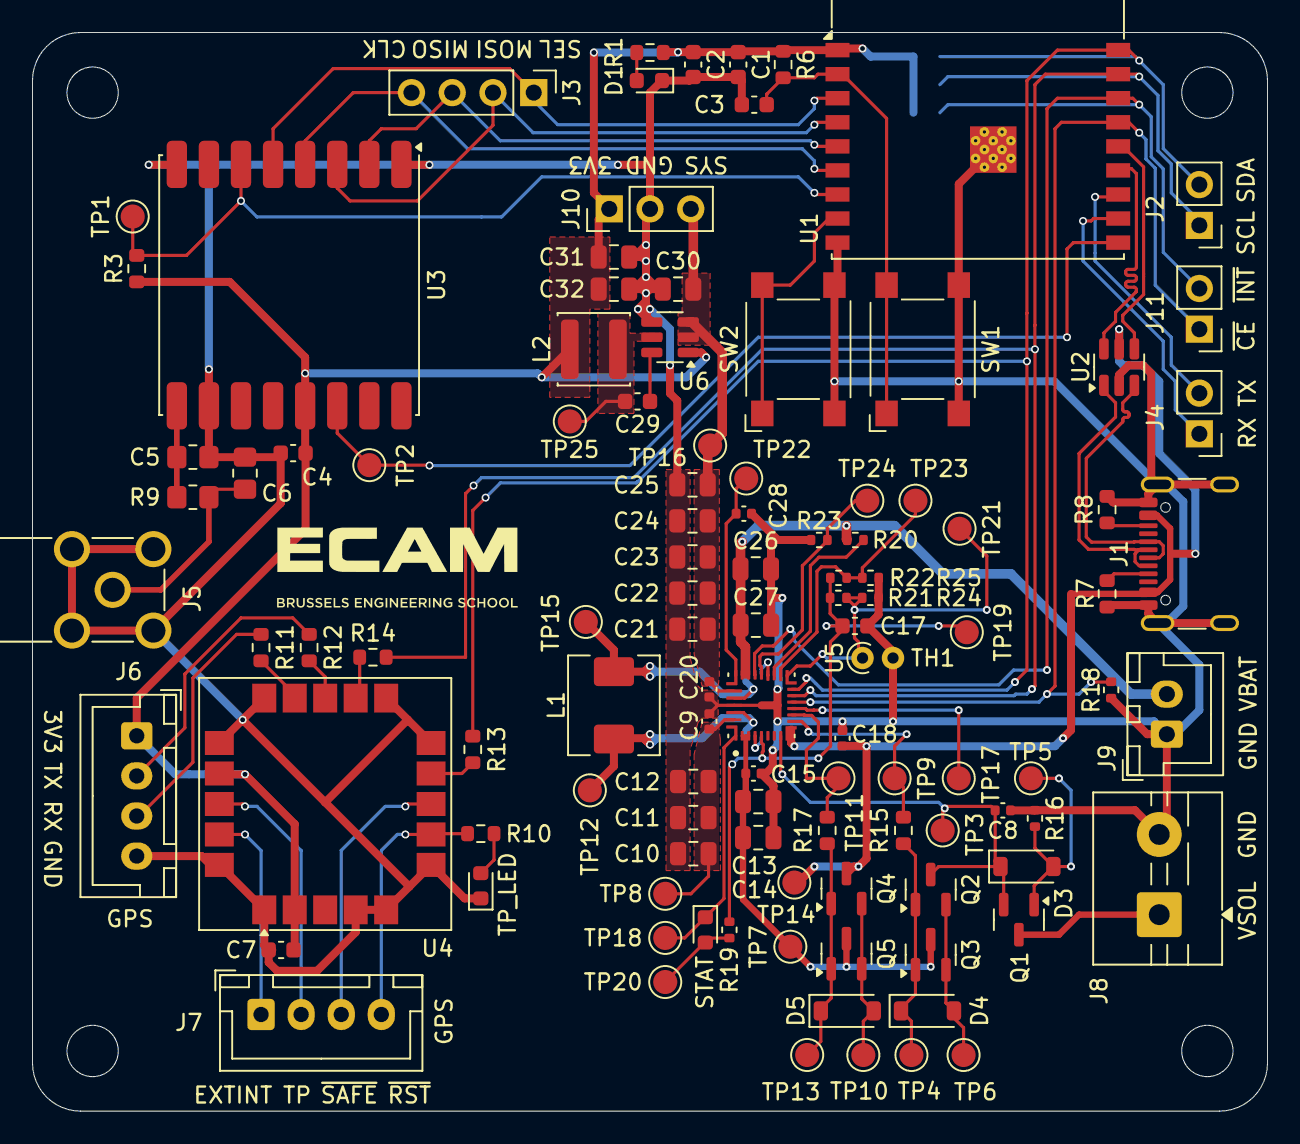
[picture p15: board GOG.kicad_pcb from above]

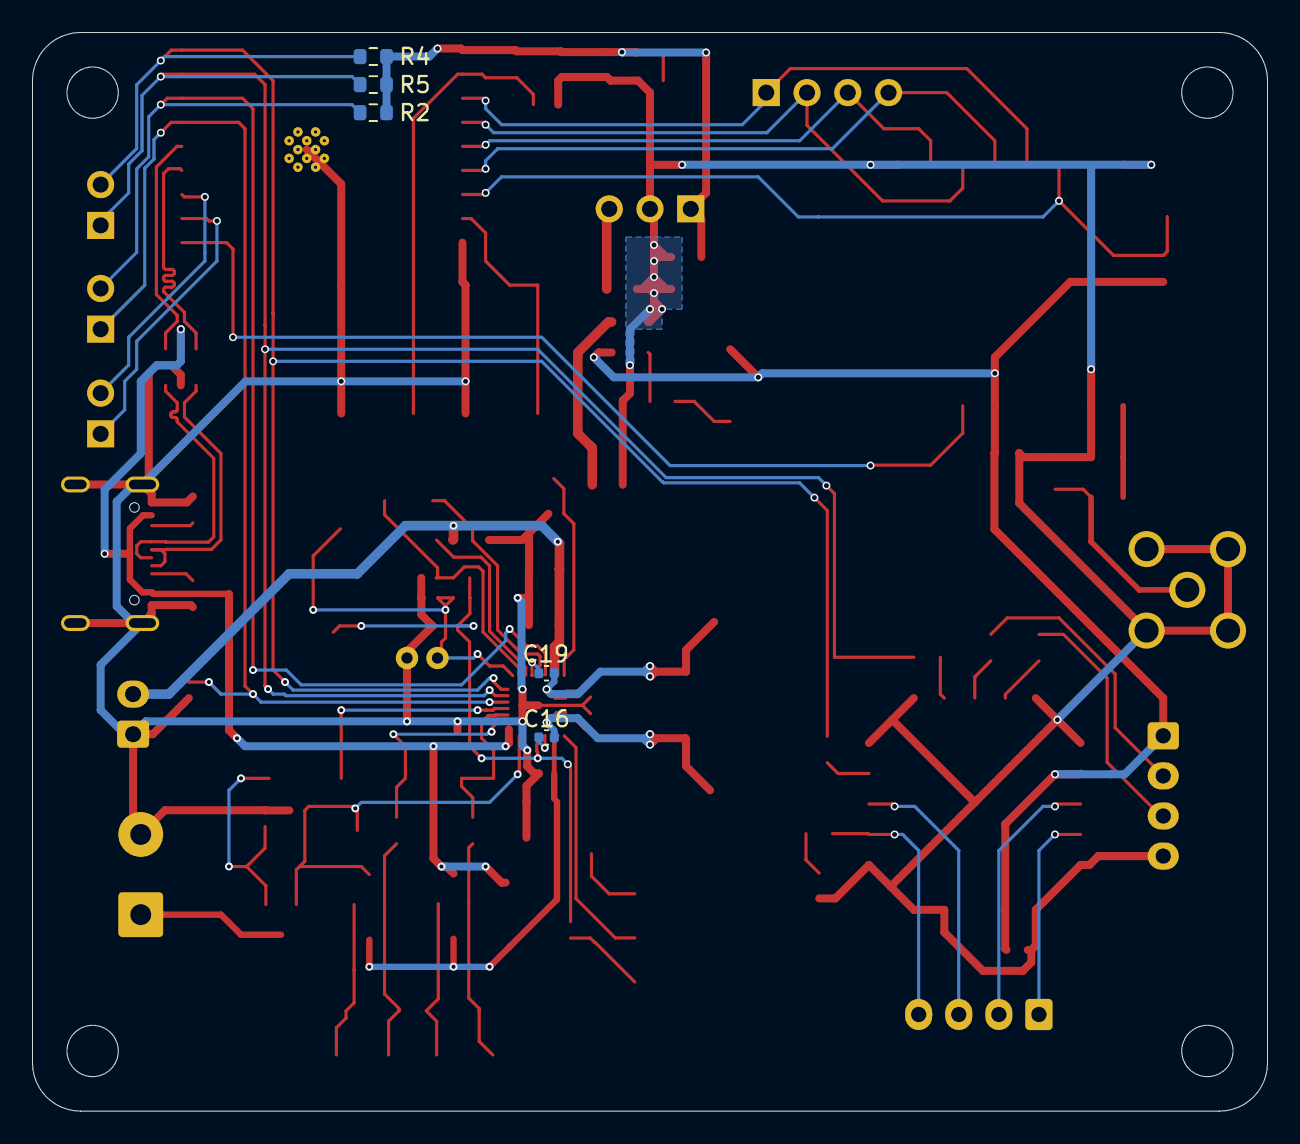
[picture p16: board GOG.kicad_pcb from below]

Board: 2 copper layers, 77.0 x 67.2 mm, 115 parts (5 on the bottom side), 65 nets.

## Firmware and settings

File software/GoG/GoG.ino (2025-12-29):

/*********
  Rui Santos & Sara Santos - Random Nerd Tutorials
  Modified from the examples of the Arduino LoRa library
  More resources: https://RandomNerdTutorials.com/esp32-lora-rfm95-transceiver-arduino-ide/
*********/

#include <SPI.h>
#include <LoRa.h>
#include <Wire.h>

//define the pins used by the transceiver module
#define sck 7 // GPIO7 on ESP32
#define miso 6 // GPIO6 on ESP32
#define mosi 5 // GPIO5 on ESP32
#define ss 4 // GPIO4 on ESP32
#define rst 8 // GPIO8 on ESP32
#define dio0 10 // GPIO10 on ESP32

int counter = 0;

void setup() {
  //initialize Serial Monitor
  Serial.begin(115200);
  while (!Serial);

  Serial.println("LoRa Sender");

  SPI.begin(sck, miso, mosi, ss);

  //setup LoRa transceiver module
  LoRa.setPins(ss, rst, dio0);
  
  //replace the LoRa.begin(---E-) argument with your location's frequency 
  //433E6 for Asia
  //868E6 for Europe
  //915E6 for North America
  while (!LoRa.begin(868E6)) {
    Serial.println(".");
    delay(500);
  }
   // Change sync word (0xF3) to match the receiver
  // The sync word assures you don't get LoRa messages from other LoRa transceivers
  // ranges from 0-0xFF
  LoRa.setSyncWord(0xF3);
  Serial.println("LoRa Initializing OK!");
}

void loop() {
  Serial.print("Sending packet: ");
  Serial.println(counter);

  //Send LoRa packet to receiver
  LoRa.beginPacket();
  LoRa.print("hello ");
  LoRa.print(counter);
  LoRa.endPacket();

  counter++;

  delay(5000);
}

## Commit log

2025-09-24 Create .gitignore for KiCad project
    Add a .gitignore file for KiCad project files and temporary files.
2025-09-24 Update project structure
    [ESP32.kicad_sch, GOG.kicad_pcb, GOG.kicad_sch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]
2025-09-26 New usb port
    [ESP32.kicad_sch]
2025-09-26 Main modules added + Com lines
    [ESP32.kicad_sch, GPS_Module.kicad_sch, Lora_Module.kicad_sch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]
2025-09-28 Basic 2 inputs source battery charger
    [Power.kicad_sch]
2025-10-02 Pull up resistor i2c
    [ESP32.kicad_sch]
2025-10-02 GPS schematic + datasheet
    [GPS_Module.kicad_sch, Lora_Module.kicad_sch]
2025-10-02 ESL protection modification with usblc6 2sc6
    [ESP32.kicad_sch, GPS_Module.kicad_sch]
2025-10-02 Change of esp32 footprint for wifi antenna
    [ESP32.kicad_sch]
2025-10-06 Added IN current limit & switching freq
    [Power.kicad_sch]
2025-10-06 Created project library & MDA5030-2R2M footprint
2025-10-06 Added BQ25798 integrated buck-boost inductor
    [Power.kicad_sch]
2025-10-06 Add SYS output capacitors & cap. package sizes
    [Power.kicad_sch]
2025-10-06 Add 2S battery circuit
    [Power.kicad_sch]
2025-10-06 Added solar input protection & diodes footprints
    [Power.kicad_sch]
2025-10-06 Updated BQ25798 pins location
    [Power.kicad_sch]
2025-10-06 Add BQ25798 debug pins to ESP and placed TP & headers
    [ESP32.kicad_sch, Power.kicad_sch]
2025-10-06 Add shunt resistor current sensing to solar input
    [Power.kicad_sch]
2025-10-07 Added battery NTC thermistor footprint
    [Power.kicad_sch]
2025-10-07 Started 5V/3.3V buck & add components to lib
    [Power.kicad_sch, SRP4020TA-5R6M.step]
2025-10-11 Finished 3.3V/5V buck design
    [Power.kicad_sch]
2025-10-13 Made symbol space for capacitors
2025-10-13 Found all capacitors & inductors footprint & JLCPCB
    [ESP32.kicad_sch, GPS_Module.kicad_sch, Lora_Module.kicad_sch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]
2025-10-13 Found all resistors & pin headers footprint & JLCPCB
    [ESP32.kicad_sch, GPS_Module.kicad_sch, Lora_Module.kicad_sch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]
2025-10-14 Found all diodes & transistors footprint & JLCPCB
    [ESP32.kicad_sch, GOG.kicad_sch, GPS_Module.kicad_sch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]
2025-10-14 Add JLCPCB Design Rules
    [GOG.kicad_pcb]
2025-10-16 Module Lora
    [ESP32.kicad_sch, Lora_Module.kicad_sch, Power.kicad_sch]
2025-10-16 Update ESP32 pins
    [85201239.step, ESP32.kicad_sch, GPS_Module.kicad_sch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]
2025-10-17 Ref composant JLCBPCB LoRa
    [Lora_Module.kicad_sch]
2025-10-18 Setup PCB design parameters
    [ESP32.kicad_sch]
2025-10-18 Fix schematic components annotations
    [ESP32.kicad_sch, GPS_Module.kicad_sch, Lora_Module.kicad_sch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]
2025-10-18 Fix all ERC errors
    [ESP32.kicad_sch, Lora_Module.kicad_sch, Power.kicad_sch]
2025-10-18 Fix several DRC errors & add all 3D models
    [BQ25798RQMR.step, GOG.kicad_pcb, GPS_Module.kicad_sch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]
2025-10-19 Finished battery manager placement
    [GOG.kicad_pcb, Lora_Module.kicad_sch, Power.kicad_sch]
2025-10-19 Created ECAM logo as footprint
2025-10-19 Finished optimal placement & adapted/fixed schematic
    [GOG.kicad_pcb, GPS_Module.kicad_sch, Lora_Module.kicad_sch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]
2025-10-19 Finished PCB routing
    [GOG.kicad_pcb, Power.kicad_sch]
2025-10-20 Find all remaining components on JLCPCB
    [ESP32.kicad_sch, GOG.kicad_pcb, GPS_Module.kicad_sch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]
2025-10-20 Gerber fabrication outputs
    [BOM.xlsx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]
2025-11-26 Add inverted F antenna simulation
2025-12-17 Fix ESP to RFM95 pins
    [GoG.ino]
2025-12-17 Fix SPI pins blocking communication to LoRa module
    [GoG.ino]
2026-01-19 Created README with project results
    Added detailed project description, specifications, hardware used, antenna simulation, and validation results.
